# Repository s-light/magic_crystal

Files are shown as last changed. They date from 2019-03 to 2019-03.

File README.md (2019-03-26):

<!--lint disable list-item-indent-->
<!--lint disable list-item-bullet-indent-->

# magic_crystal
CAD design for magic sparkle crystal

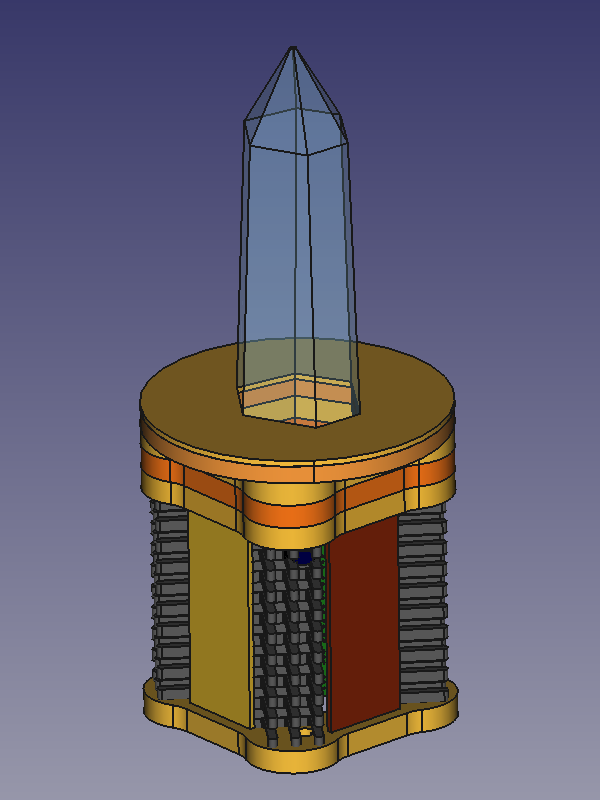
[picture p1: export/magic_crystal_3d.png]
magic crystal

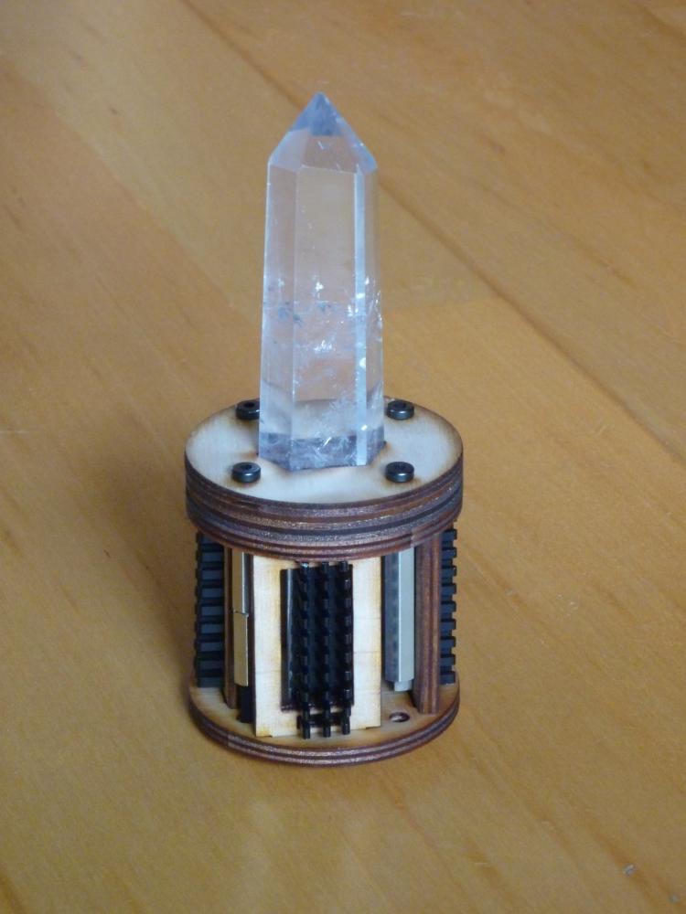
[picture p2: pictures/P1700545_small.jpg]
first fit-test


more images in the [gallery](gallery.md)

## Software
have a look at [magic_crystal_animation](https://github.com/s-light/magic_crystal_animation)

## Hardware
- 4x [LEDBoard_4x4_HD](https://github.com/s-light/LEDBoard_4x4_HD)
- 4x 1/3-part of Heatsink [ICK PGA 14 x 14 x 12](https://www.fischerelektronik.de/web_fischer/de_DE/K%C3%BChlk%C3%B6rper/B01/K%C3%BChlk%C3%B6rper%20f%C3%BCr%20PGA/PR/ICKPGA14x14x12_/parameters/index.xhtml/) ([3d-model](https://github.com/s-light/LEDBoard_4x4_16bit/tree/master/parts/mechanical))
- 8x [nut M3](https://www.wegertseder.com/ArticleDetails.aspx?ANR=4445-100)
- 8x [screw M3x20](https://www.wegertseder.com/ArticleDetails.aspx?AKNUM=2588&Diameter=3)
- lasercut wood  
    have a look at the [export/](export/) folder for the files
    - 4mm plywood
        - 1x crystal_mounting_layer1
        - 1x crystal_mounting_layer2
        - 1x crystal_mounting_layer3
        - 1x lightguides_mounting
        - 1x bottom
    - 1mm plywood
        - 4x lightblocker_side
        - 1x crystal_mounting_layer4
- electronics
    - 1x [Adafruit ItsyBitsy M4](https://learn.adafruit.com/introducing-adafruit-itsybitsy-m4)  
    or other CircuitPython compatible board  
    (Arduino firmware not done yet..)
    - 1x ambient-light-sensor (to be defined)
    - 2x momentary-push-button
    - DC-DC converter [Pololu 5V, 5A Step-Down Voltage Regulator D24V50F5](https://www.pololu.com/product/2851)
    - batteries
        - for first tests 4x older version of [Lithium Ion Cylindrical Battery - 3.7v 2200mAh](https://www.exp-tech.de/en/accessories/batteries/lipo/7391/lithium-ion-cylindrical-battery-3.7v-2200mah?c=1191)  
        the older version has a maximal discharge current of ~500mA  
        so it is only possible to use the LEDBoards with low power setting..  
        4 \* 6W = 24W → 27W (input with loss of DC/DC converter)  
        4 \* 3.7V = 14,8V → 1,8 A  
        (4 \* 3.7V) \* 0,5A = 5,92 W  
        - later eventually switching to LiFePo4  
        most likely to 18650 or 26650 2x 2s1p inline packs  
        (similar to [4s1p A123 ANR26650M1B 2x2-Pack 13,2V 2,5Ah](https://www.asn-shop.de/4s1p-A123-ANR26650M1B-2x2-Pack-132V-25Ah))

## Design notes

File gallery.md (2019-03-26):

<!--lint disable list-item-indent-->
<!--lint disable list-item-bullet-indent-->

# Gallery
Some impressions of the parts and the build process...

<!-- TOC depthFrom:2 depthTo:6 withLinks:1 updateOnSave:1 orderedList:0 -->

- [CAD](#cad)
- [REAL](#real)
	- [current design](#current-design)
	- [first design](#first-design)
- [lightguides](#lightguides)
- [assembly](#assembly)

<!-- /TOC -->

## CAD
magic crystal

## REAL

### current design

TODO: take picture of final result ;-)

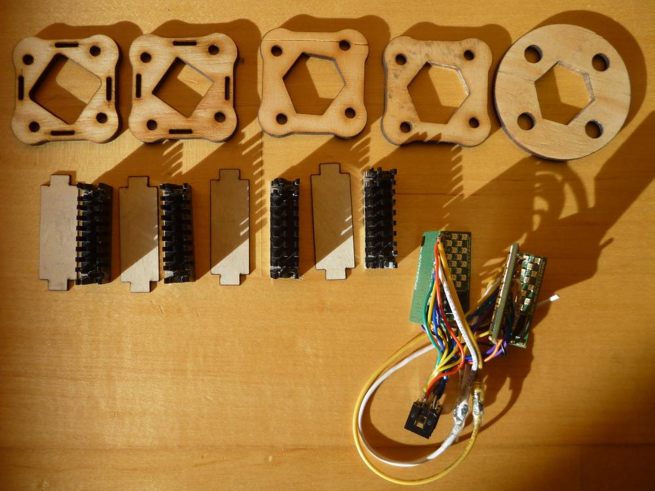
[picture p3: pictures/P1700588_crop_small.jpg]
assembly preparations


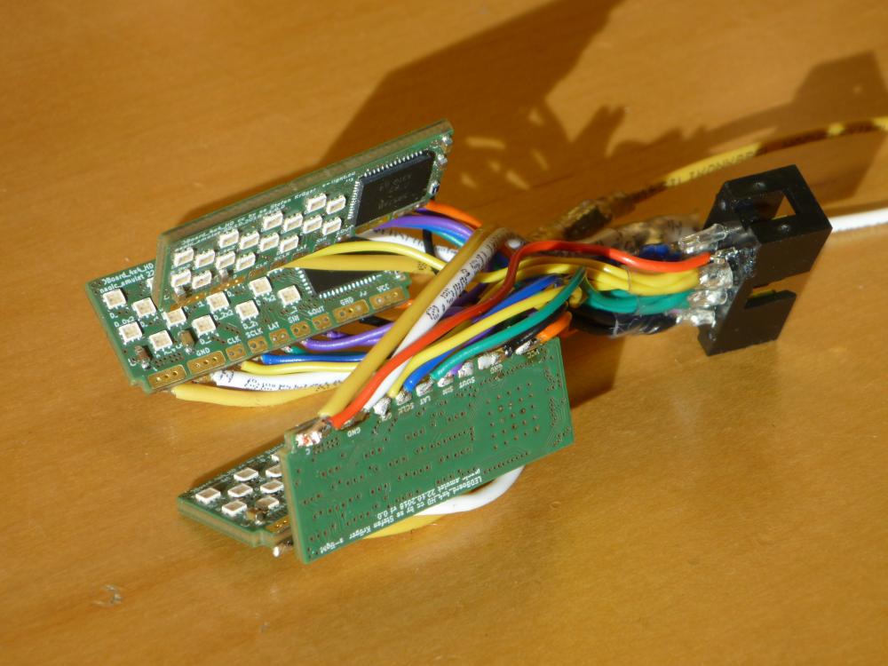
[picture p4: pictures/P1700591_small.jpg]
LEDBoards details


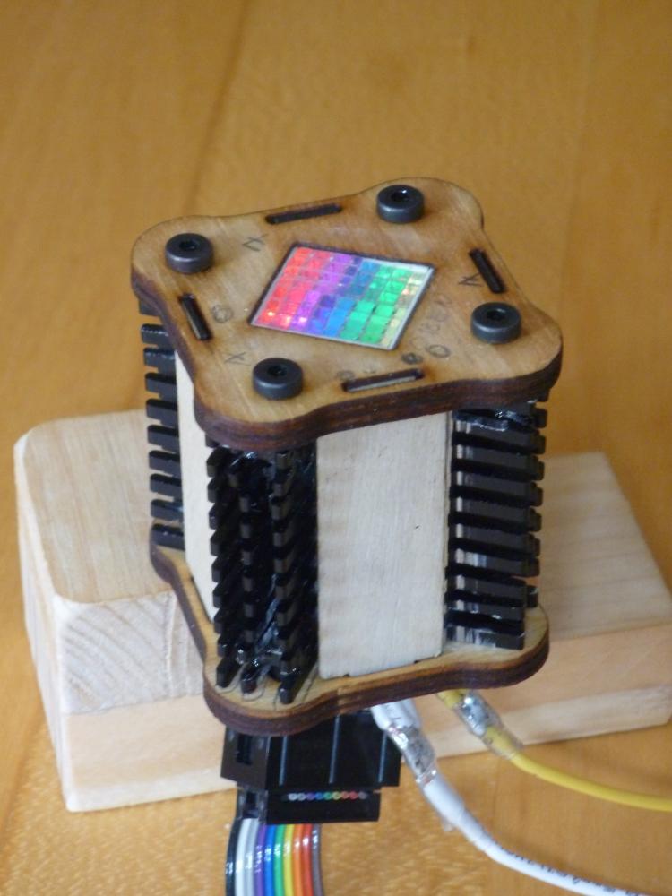
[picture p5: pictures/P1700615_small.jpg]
done :-)


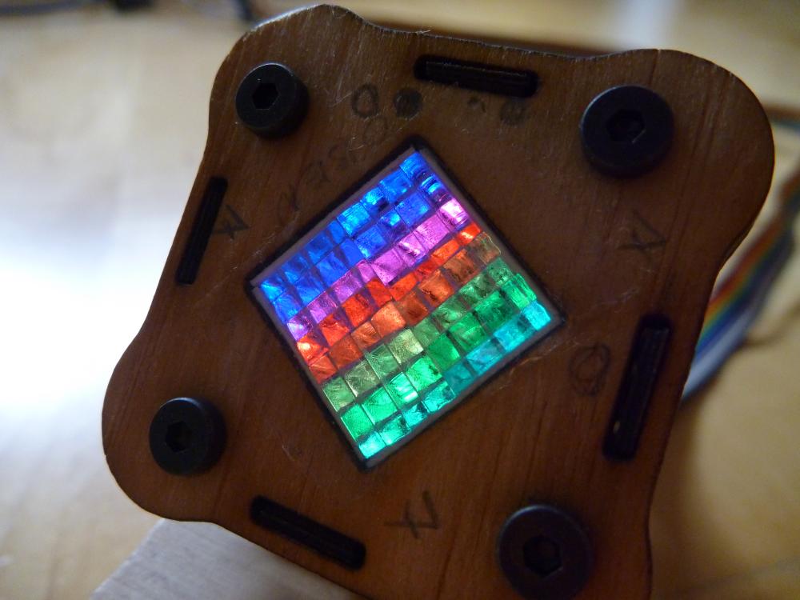
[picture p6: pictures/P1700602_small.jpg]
matrix details


### first design

first fit-test

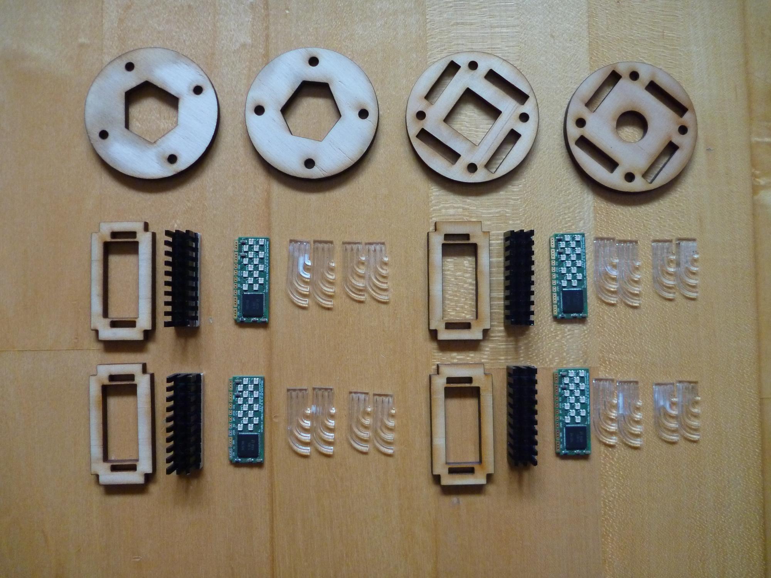
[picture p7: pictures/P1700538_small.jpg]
art-work assembly preparations


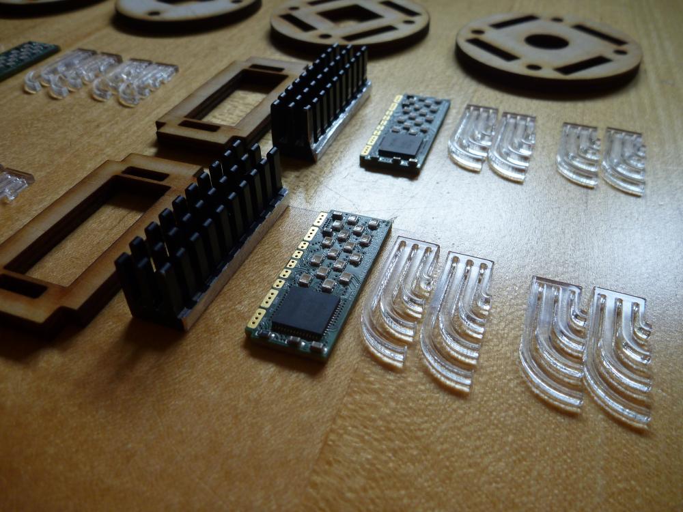
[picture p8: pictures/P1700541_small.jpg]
art-work assembly preparations details


## lightguides

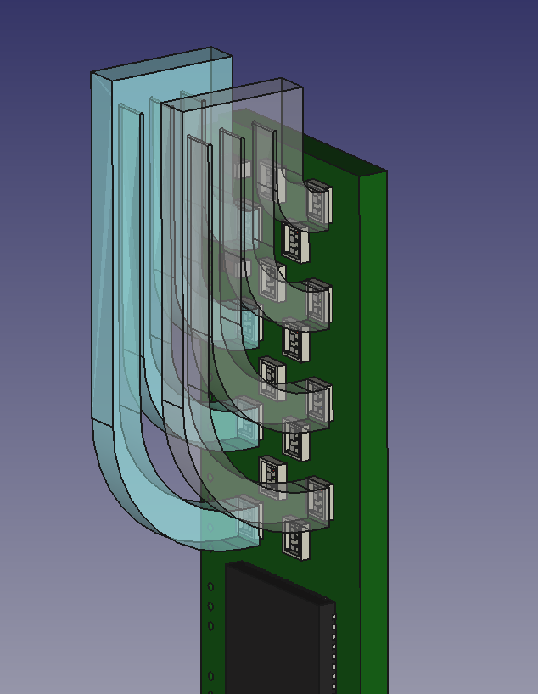
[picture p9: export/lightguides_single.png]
details lightguides


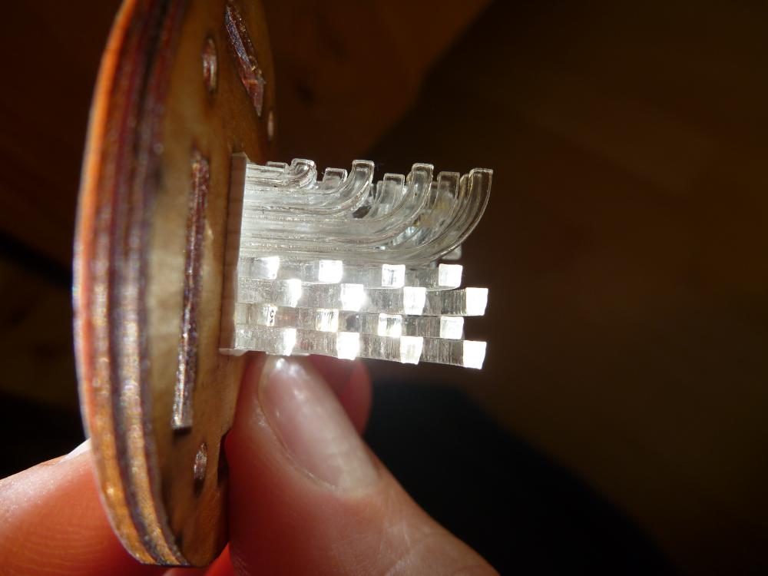
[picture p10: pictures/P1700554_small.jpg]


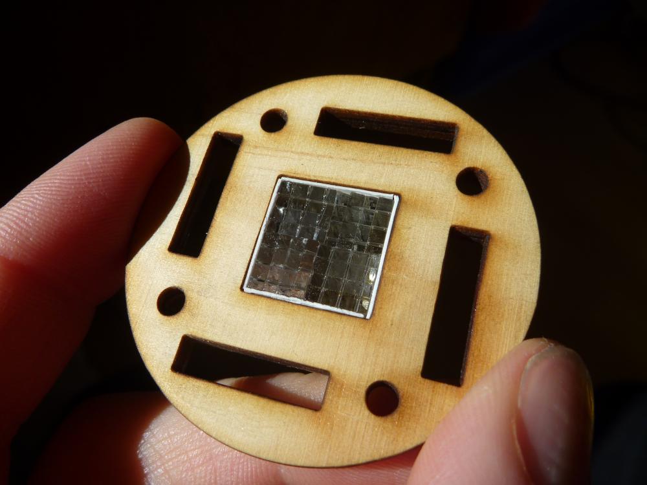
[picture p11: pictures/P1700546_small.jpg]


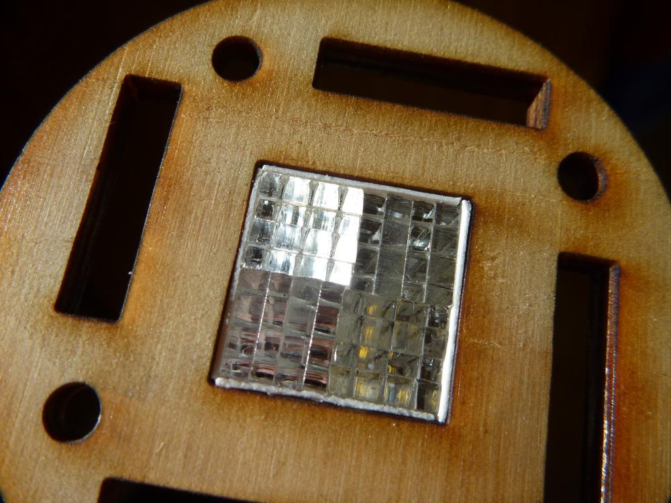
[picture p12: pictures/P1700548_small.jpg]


## assembly
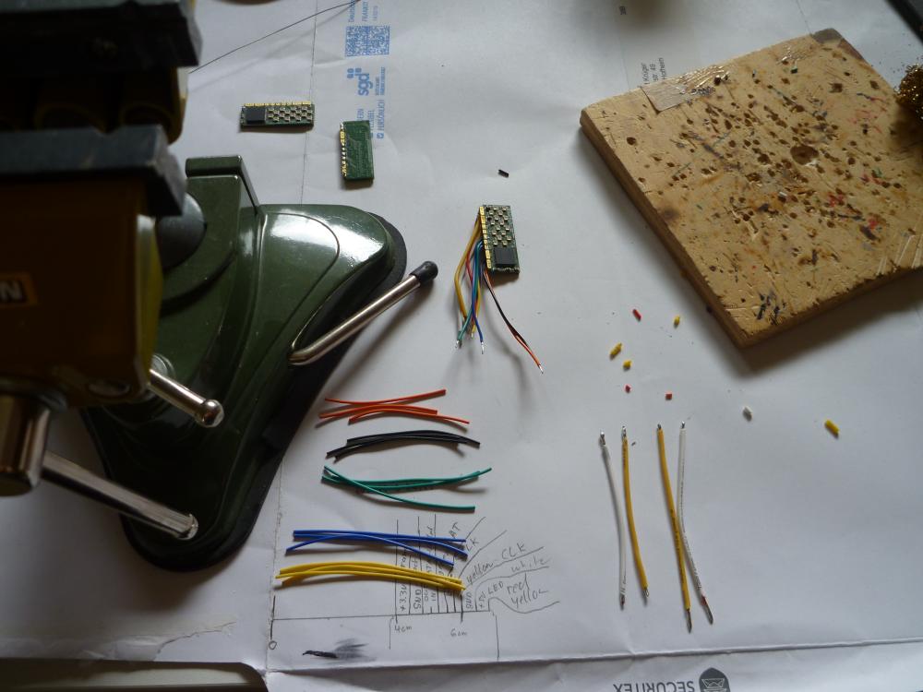
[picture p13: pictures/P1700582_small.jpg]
prepare lots of cables


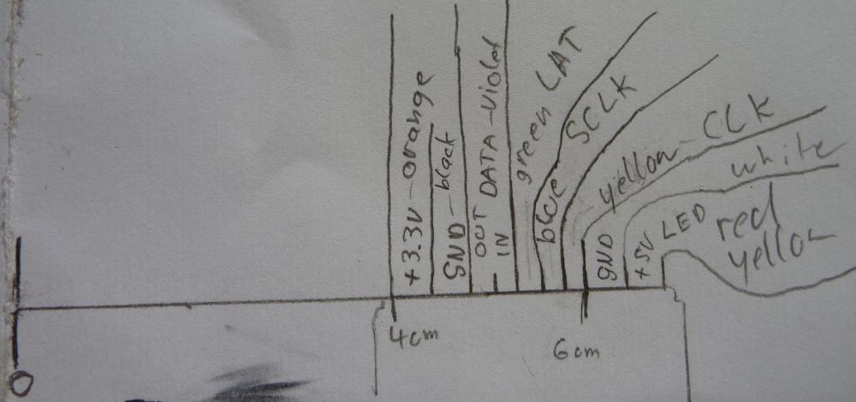
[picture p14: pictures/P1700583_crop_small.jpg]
pinout


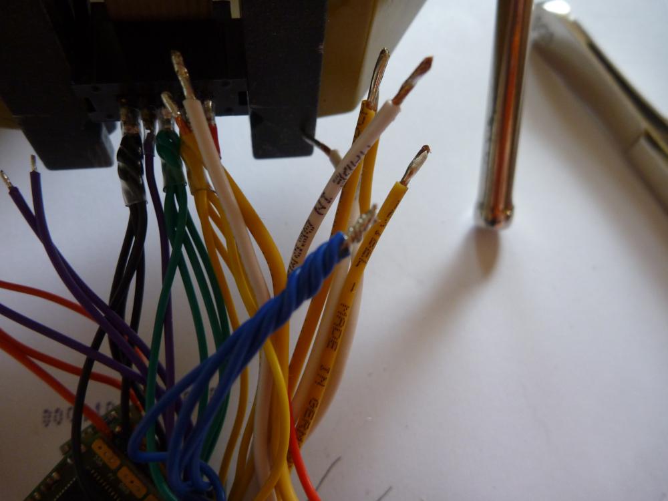
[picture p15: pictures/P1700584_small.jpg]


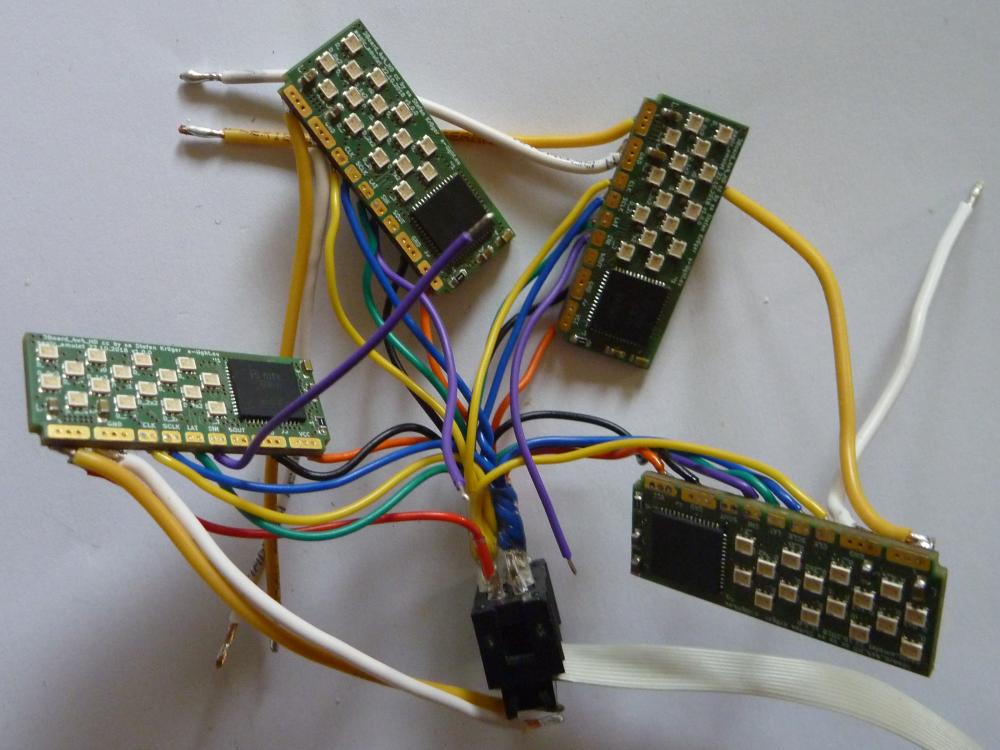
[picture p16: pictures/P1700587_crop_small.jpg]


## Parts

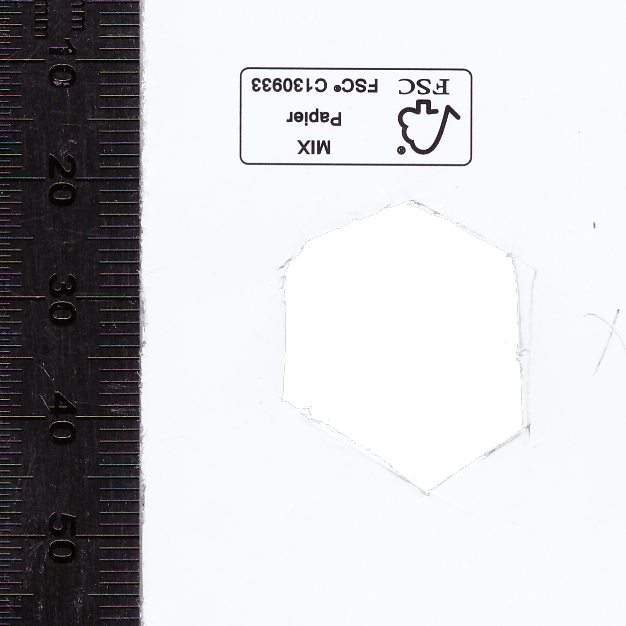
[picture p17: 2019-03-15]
parts/crystal_outline_at_11mm.png

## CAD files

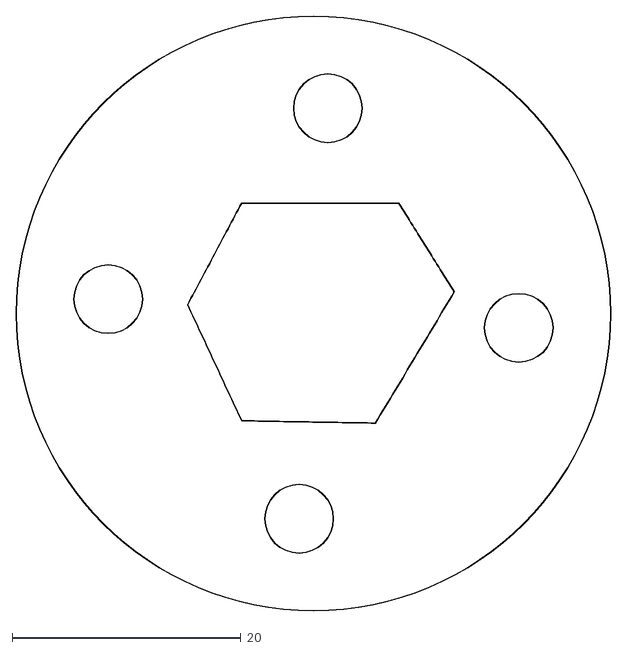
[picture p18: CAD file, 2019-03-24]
export/crystal_mounting_layer3.dxf
52.0 x 52.0

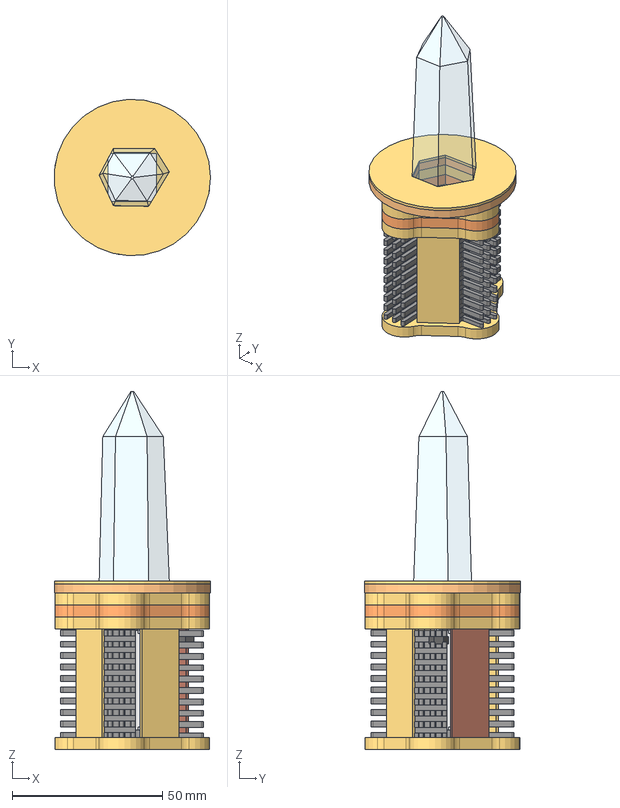
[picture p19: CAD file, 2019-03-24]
magic_crystal.FCStd
51.9 x 51.9 x 119.0 mm
lightguide_layer1_Body
lightguide_layer2_Body
lightguide_layer3_Body
lightguide_layer4_Body
LEDBoard_4x4_HD_simplified2
LEDBoard_4x4_HD_simplified3
LEDBoard_4x4_HD_simplified4
LEDBoard_4x4_HD_simplified1
HeatSink_Part_Cut_V1_Body1
HeatSink_Part_Cut_V1_Body002
HeatSink_Part_Cut_V1_Body003
HeatSink_Part_Cut_V1_Body004
crystal_detailed_Body_SimpleCopy
crystal_mounting_layer_1_Body
crystal_mounting_layer_2_Body
lightguides_mounting_Body
lightblocker_side_Body
lightblocker_side_Clone2
lightblocker_side_Clone3
lightblocker_side_Clone4
bottom_Body
M3_Nut_Clone
crystal_mounting_layer_4_Body
crystal_mounting_layer_3_Body

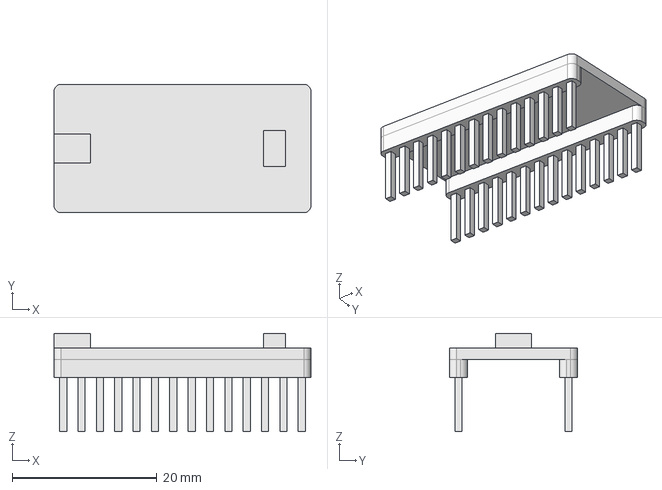
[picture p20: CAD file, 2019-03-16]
parts/Adafruit_ItsyBitsy_M4.FCStd
35.6 x 17.8 x 13.6 mm

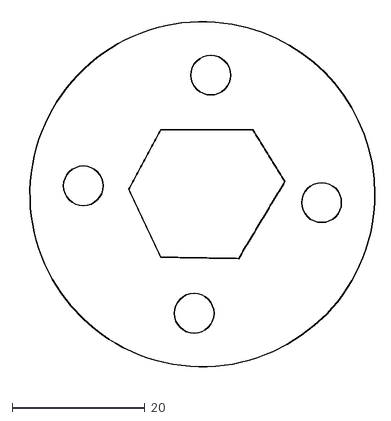
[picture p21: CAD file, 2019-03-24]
export/crystal_mounting_layer2.dxf
54.1 x 54.9

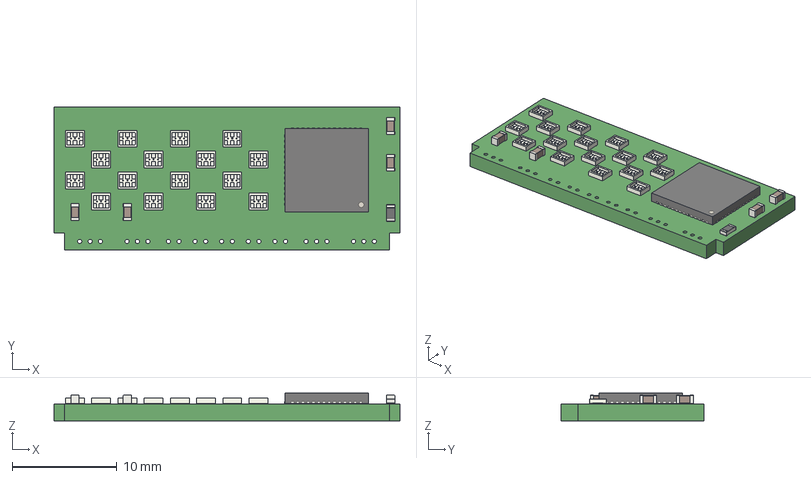
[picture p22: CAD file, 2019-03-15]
parts/LEDBoard_4x4_HD.step
33.0 x 13.6 x 2.65 mm

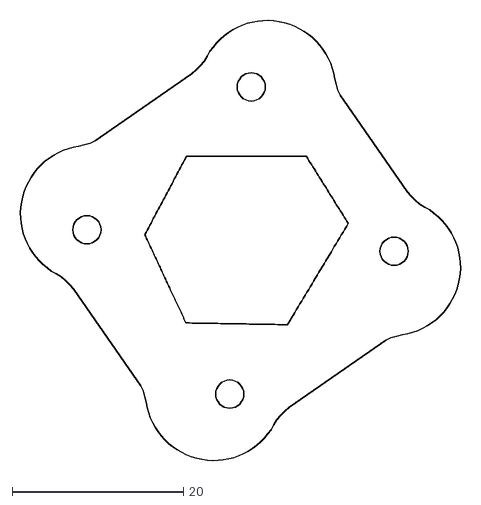
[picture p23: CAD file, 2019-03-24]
export/crystal_mounting_layer1.dxf
52.4 x 52.4

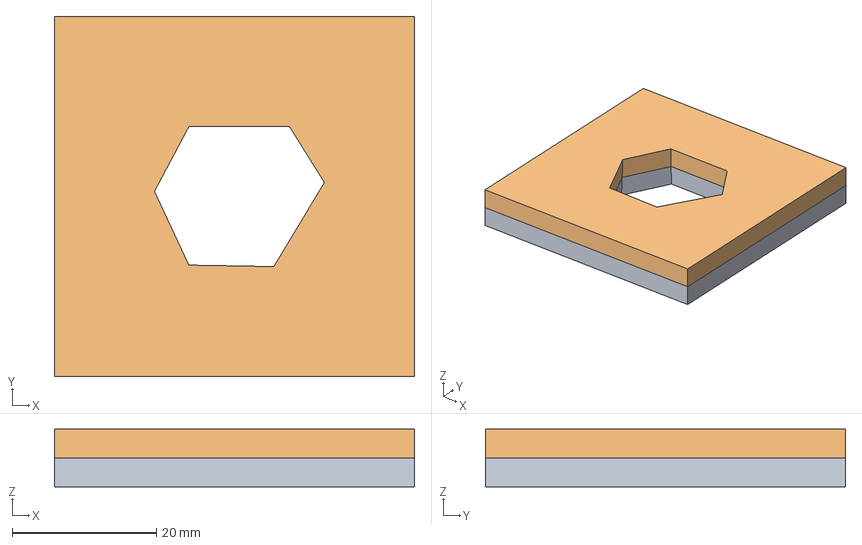
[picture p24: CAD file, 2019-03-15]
parts/crystal.FCStd
50.0 x 50.0 x 8.00 mm
mounting_plate_bottom_4mm_Body
mounting_plate_top_4mm_Body

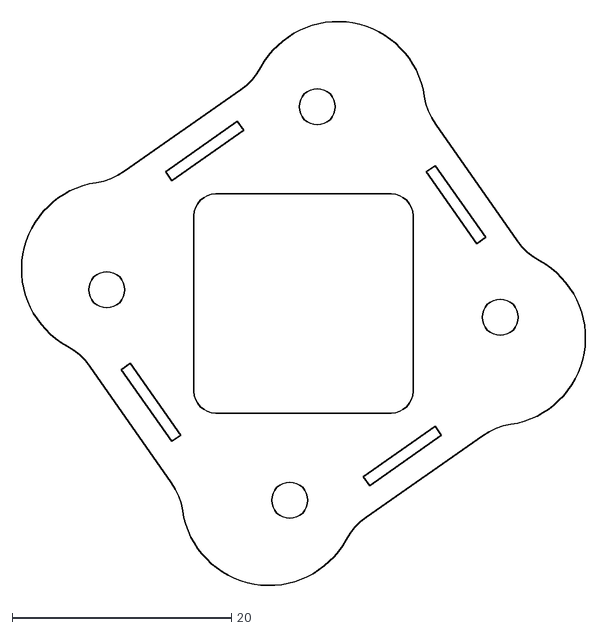
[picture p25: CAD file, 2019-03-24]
export/bottom.dxf
52.4 x 52.4

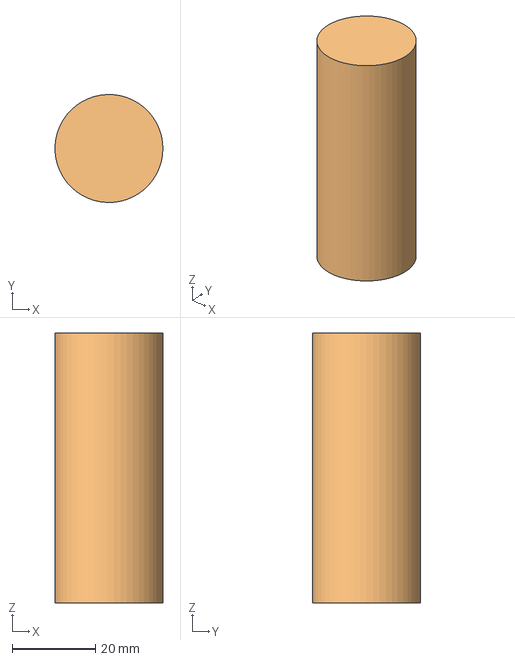
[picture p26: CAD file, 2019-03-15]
parts/batteries.FCStd
26.0 x 26.0 x 65.0 mm
battery_18650_Body
battery_26650_Body001

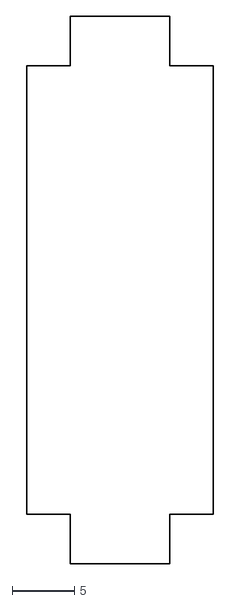
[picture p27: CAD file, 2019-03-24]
export/lightblocker_side.dxf
15.0 x 44.0

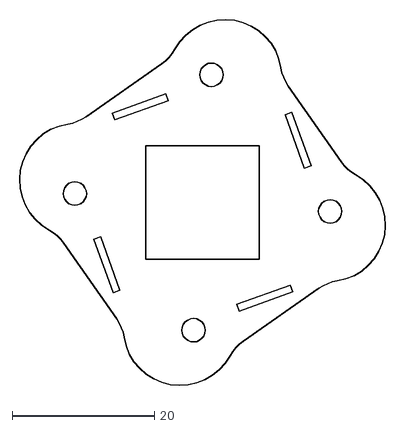
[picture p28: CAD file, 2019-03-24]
export/lightguides_mounting.dxf
52.4 x 52.4

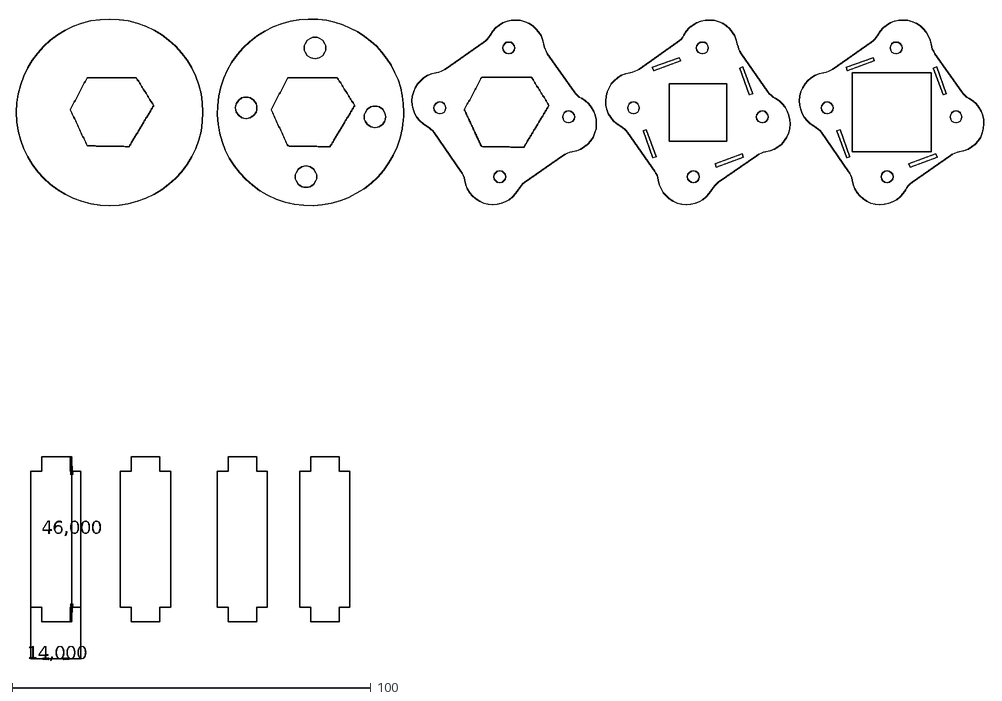
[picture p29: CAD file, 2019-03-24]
export/drawing_mountings.dxf
46,000
14,000

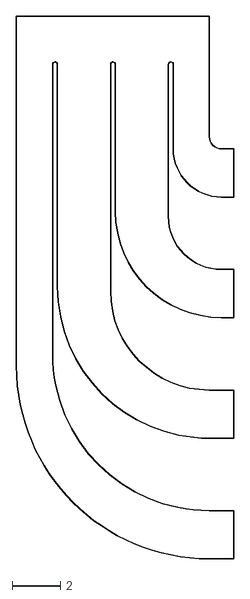
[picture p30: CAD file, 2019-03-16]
export/lightguide_layer2.dxf
9.00 x 22.5

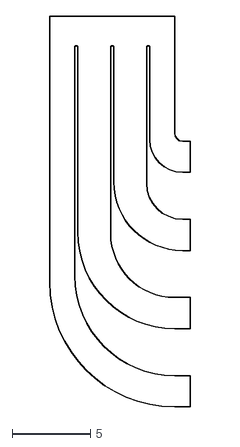
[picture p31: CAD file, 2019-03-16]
export/lightguide_layer1.dxf
9.00 x 25.0

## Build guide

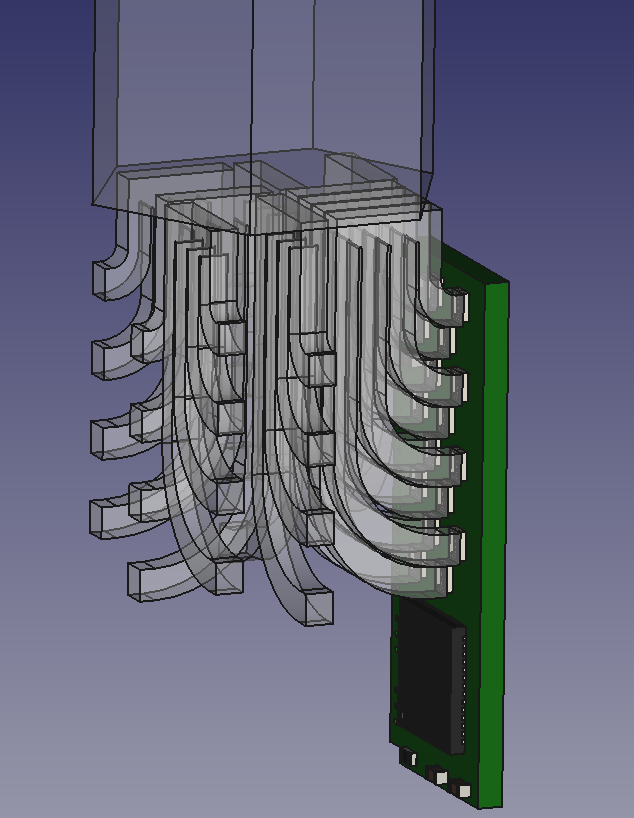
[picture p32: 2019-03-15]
export/lightguides_sketch_overview.png

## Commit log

2019-03-15 created model of crystal
    [crystal.FCStd]
2019-03-15 done for today..
    [LEDBoard_4x4_HD.step, batteries.FCStd, crystal.FCStd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]
2019-03-16 more cad construction
    [Adafruit_ItsyBitsy_M4.FCStd, magic_crystal.FCStd]
2019-03-16 more mounting construction
    [magic_crystal.FCStd]
2019-03-16 mounting finished
    [magic_crystal.FCStd]
2019-03-16 export created
    [bottom.dxf, crystal_mounting_layer1.dxf, crystal_mounting_layer2.dxf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]
2019-03-17 clean up export folder + add lightburn files
    [crystal_mounting_layer1_.dxf, crystal_mounting_layer2_.dxf, magic_crystal.FCStd]
2019-03-18 updated images
    [magic_crystal.FCStd]
2019-03-18 reorganize folders
    [Adafruit_ItsyBitsy_M4.FCStd, LEDBoard_4x4_HD.step, batteries.FCStd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]
2019-03-18 rename components → parts
    [Adafruit_ItsyBitsy_M4.FCStd, LEDBoard_4x4_HD.step, batteries.FCStd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]
2019-03-18 new image
    [magic_crystal.FCStd]
2019-03-23 CAD changes
    [magic_crystal.FCStd]
2019-03-24 more cad changes & export
    [crystal_mounting_layer1.dxf, crystal_mounting_layer2.dxf, crystal_mounting_layer3.dxf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]
2019-03-24 more export / cut preparations
    [crystal_mounting_layer1_offset.dxf, crystal_mounting_layer2_offset.dxf, heatsink_mounting.dxf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]
2019-03-24 fix lightblocker + export
    [bottom.dxf, lightblocker_side.dxf, magic_crystal.FCStd]
2019-03-24 fix crystal offset
    [crystal_mounting_layer1.dxf, crystal_mounting_layer1_offset.dxf, crystal_mounting_layer2.dxf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]
2019-03-24 laser done.
2019-03-24 updated image
    [magic_crystal.FCStd]
2019-03-26 [gallery] add assemble pictures
